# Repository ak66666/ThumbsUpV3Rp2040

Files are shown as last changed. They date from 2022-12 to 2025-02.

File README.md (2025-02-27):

# ThumbsUp! v3 RP2040-based 4x12 keyboard for Kailh Choc switches

Multilevel 44 Key Split Contoured Keyboard.
2-key Thumb Cluster

* RP2040 is soldered on the boards.
* TRS (3-wire) audio cable to connect the halves.
* Hot swap sockets for Kailh Choc switches.
* USB-C connectors.
* Connects to computer from either side, halves could be used separately.
 
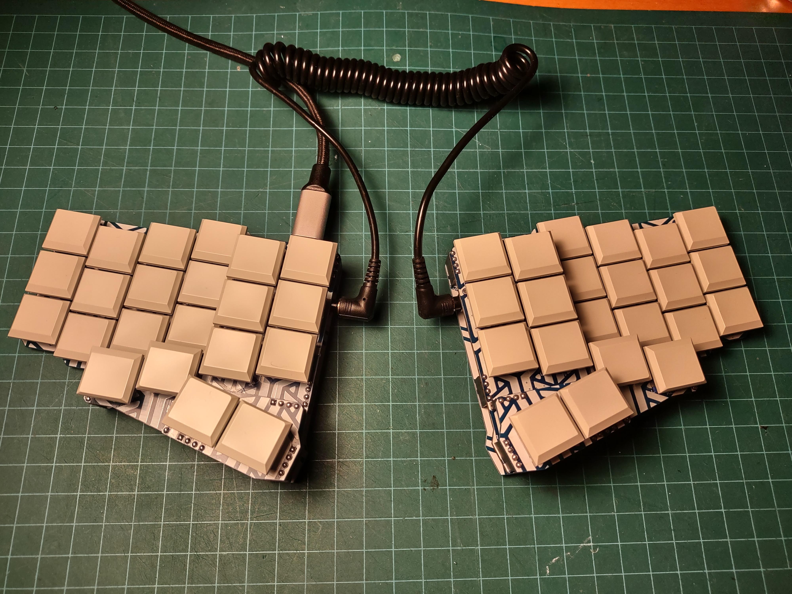
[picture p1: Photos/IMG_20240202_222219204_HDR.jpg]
Main view

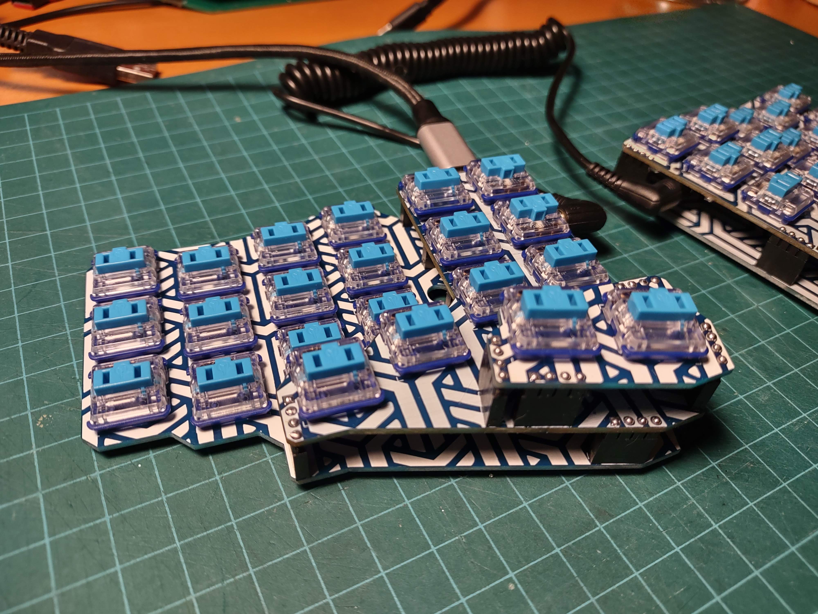
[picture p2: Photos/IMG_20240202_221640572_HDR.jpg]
Key caps removed


Other pictures in Photos folder.

# Firmware

Please refer to this article:
https://thumbsupkeyboards.blogspot.com/2024/02/source-files-and-default-firmware.html

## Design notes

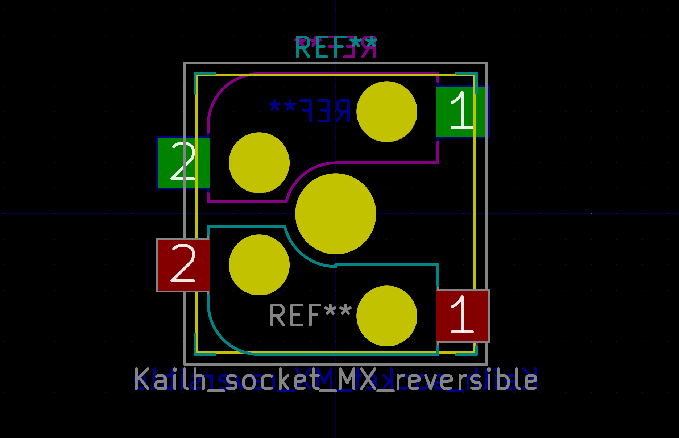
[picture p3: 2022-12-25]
keyswitches.pretty-master/images/Kailh_socket_MX_reversible_platemount.png

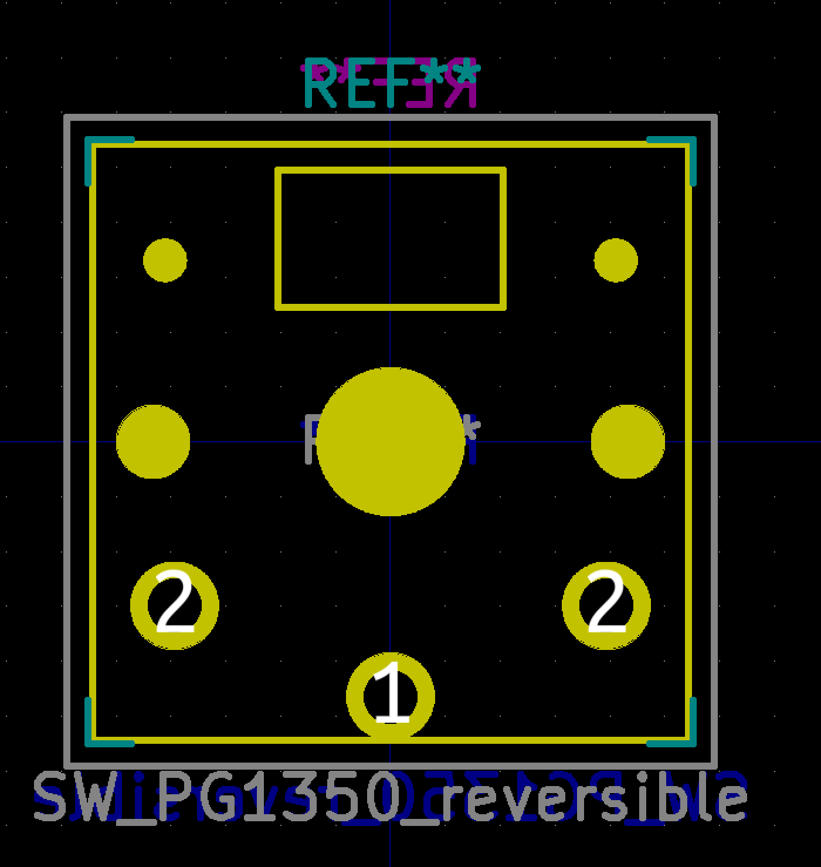
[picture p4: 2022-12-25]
keyswitches.pretty-master/images/SW_PG1350_reversible.png

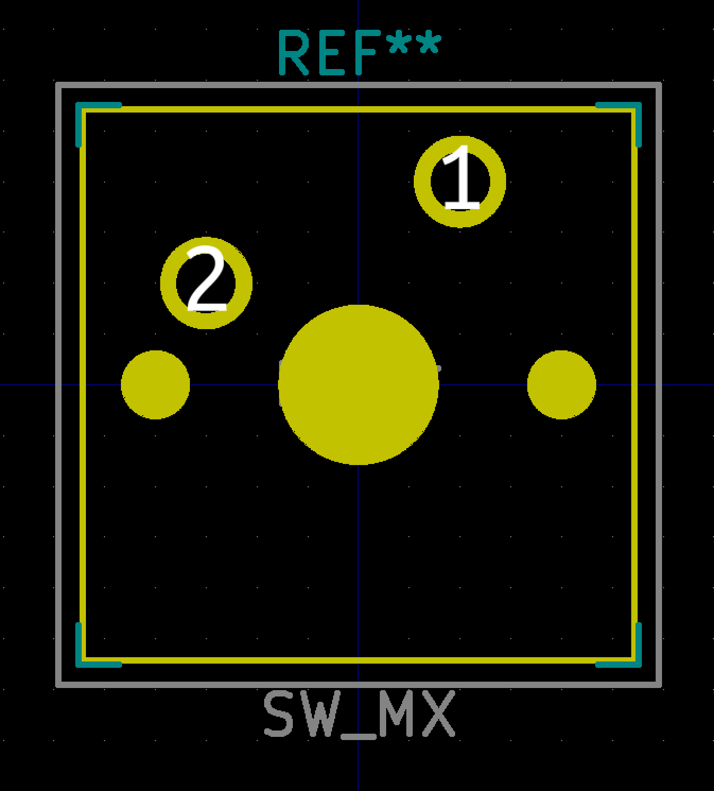
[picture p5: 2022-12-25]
keyswitches.pretty-master/images/SW_MX.png

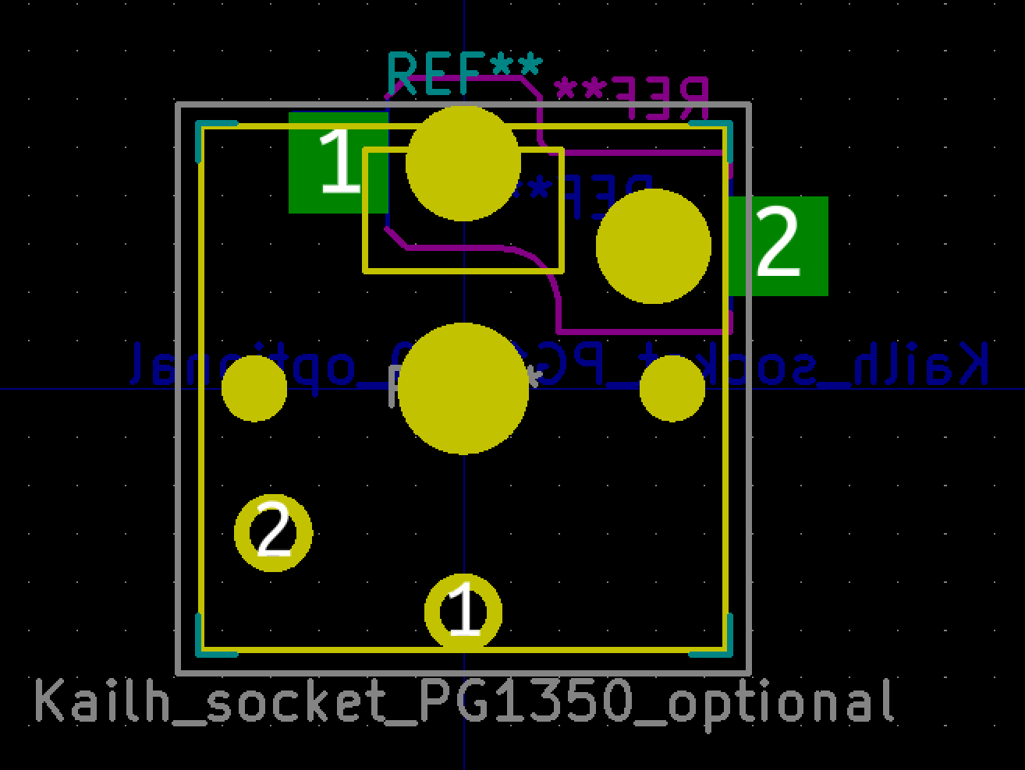
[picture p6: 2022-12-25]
keyswitches.pretty-master/images/Kailh_socket_PG1350_optional.png

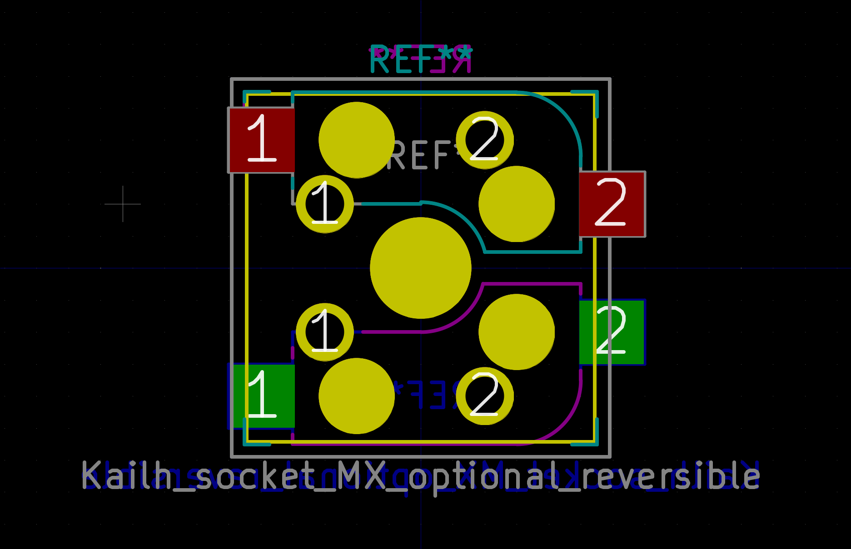
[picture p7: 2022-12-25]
keyswitches.pretty-master/images/Kailh_socket_MX_optional_reversible_platemount.png

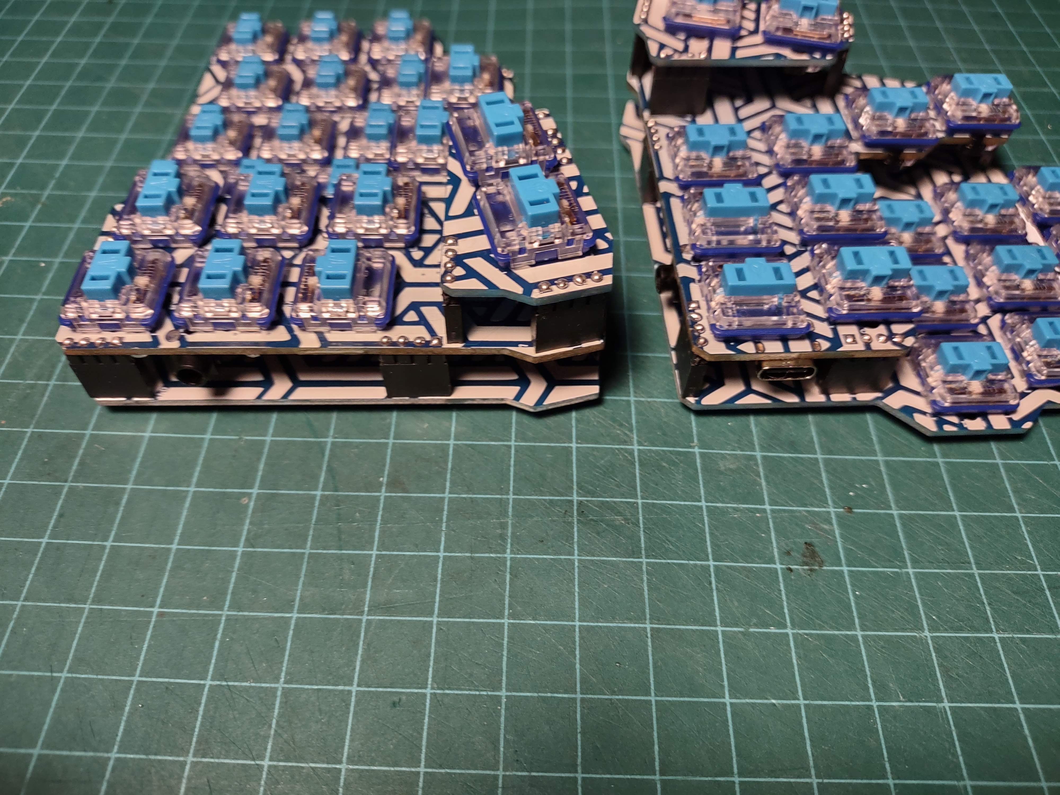
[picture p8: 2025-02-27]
Photos/IMG_20240202_221658583_HDR.jpg

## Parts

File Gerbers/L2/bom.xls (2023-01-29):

Comment | Designator | Footprint | JLCPCB Part #
27.4 | R2,R1 | R_0402_1005Metric | C274349
W25Q128JVSIM | IC2 | SOIC127P790X216-8N | C2613930
USB_C_Receptacle_USB2.0 | J32 | USB_C_Receptacle_Palconn_UTC16-G | C2927037
NCP1117-3.3_SOT223 | U1 | SOT-223-3_TabPin2 | C26537
27pF | C5,C4 | C_0402_1005Metric | C1557
1uF | C12,C3 | C_0402_1005Metric | C52923
0.1uF | C17,C16,C15,C14,C13,C10,C7,C6,C2 | C_0402_1005Metric | C2655418
5.1k | R9,R8,R4,R17,R9,R8,R4,R17 | R_0402_1005Metric | C25905
Polyfuse | F1 | Fuse_1206_3216Metric | C2836286
10uF | C11,C9 | C_0402_1005Metric | C15525
1k | R6 | R_0402_1005Metric | C11702
RP2040 | IC1 | QFN40P700X700X90-57N-D | C2040
10k | R3 | R_0402_1005Metric | C25744

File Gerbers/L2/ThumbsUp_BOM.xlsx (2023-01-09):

Comment | Designator | Footprint | JLCPCB Part #（optional）
27.4 | R2,R1 | R_0402_1005Metric
5.1k | R9,R8 | R_0402_1005Metric
10uF | C11,C9 | C_0402_1005Metric
5.1k | R4 | R_0805_2012Metric
1k | R6 | R_0402_1005Metric
10k | R3 | R_0402_1005Metric
0.1uF | C17,C16,C15,C14,C13,C10,C7,C6,C2 | C_0402_1005Metric
1uF | C12,C3 | C_0402_1005Metric
27pF | C5,C4 | C_0402_1005Metric
USB_C_Receptacle_USB2.0 | J32 | USB_C_Receptacle_Palconn_UTC16-G
STX-3501-3N | J36 | STX35013N
ABLS-12.000MHZ-B4-T | Y1 | HC%2f49US-(AT49)_1
NCP1117-3.3_SOT223 | U1 | SOT-223-3_TabPin2
TL1016AAF220QG | RUN1,BOOTSEL1 | TL1016AAF220QG
W25Q128JVSIM | IC2 | SOIC127P790X216-8N
RP2040 | IC1 | QFN40P700X700X90-57N-D
Polyfuse | F1 | Fuse_1206_3216Metric

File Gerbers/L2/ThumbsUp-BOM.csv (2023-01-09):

Id | Designator | Package | Quantity | Designation | Supplier and ref
1 | R2,R1 | R_0402_1005Metric | 2 | 27.4
2 | R9,R8 | R_0402_1005Metric | 2 | 5.1k
3 | C11,C9 | C_0402_1005Metric | 2 | 10uF
4 | R4 | R_0805_2012Metric | 1 | DNF
5 | R7 | R_0402_1005Metric | 1 | DNF
6 | R6 | R_0402_1005Metric | 1 | 1k
7 | R3 | R_0402_1005Metric | 1 | 10k
8 | C17,C16,C15,C14,C13,C10,C7,C6,C2 | C_0402_1005Metric | 9 | 0.1uF
9 | C12,C3 | C_0402_1005Metric | 2 | 1uF
10 | C5,C4 | C_0402_1005Metric | 2 | 27pF
11 | J32 | USB_C_Receptacle_Palconn_UTC16-G | 1 | USB_C_Receptacle_USB2.0
12 | J3 | PinSocket_1x04_P2.54mm_Vertical | 1 | Conn_01x04_Female
13 | J36 | STX35013N | 1 | STX-3501-3N
14 | J39,J45,J16 | PinHeader_1x04_P2.54mm_Vertical | 3 | Raiser_Male
15 | J17,J9,J13 | PinSocket_1x04_P2.54mm_Vertical | 3 | Raiser_Female
16 | MX19 | Kailh_socket_PG1350_optional | 1 | SwT
17 | MX14 | Kailh_socket_PG1350_optional | 1 | SwLALT
18 | MX15 | Kailh_socket_PG1350_optional | 1 | SwR
19 | MX17 | Kailh_socket_PG1350_optional | 1 | SwV
20 | MX20 | Kailh_socket_PG1350_optional | 1 | SwG
21 | MX21 | Kailh_socket_PG1350_optional | 1 | SwB
22 | MX10 | Kailh_socket_PG1350_optional | 1 | SwLWIN
23 | MX16 | Kailh_socket_PG1350_optional | 1 | SwF
24 | J1,J8,J2,J7 | PinHeader_1x04_P2.54mm_Vertical | 4 | Conn_01x04_Male
25 | Y1 | HC%2f49US-(AT49)_1 | 1 | ABLS-12.000MHZ-B4-T
26 | U1 | SOT-223-3_TabPin2 | 1 | NCP1117-3.3_SOT223
27 | RUN1,BOOTSEL1 | TL1016AAF220QG | 2 | TL1016AAF220QG
28 | IC2 | SOIC127P790X216-8N | 1 | W25Q128JVSIM
29 | IC1 | QFN40P700X700X90-57N-D | 1 | RP2040
30 | F1 | Fuse_1206_3216Metric | 1 | Polyfuse

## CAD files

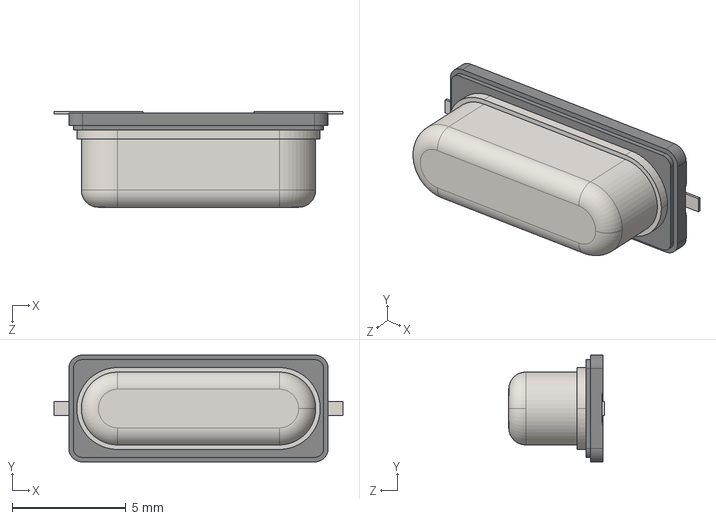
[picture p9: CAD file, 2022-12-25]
ABLS-12.000MHZ-B4-T/3D/ABLS-12.000MHZ-B4-T.stp
12.7 x 4.70 x 4.20 mm

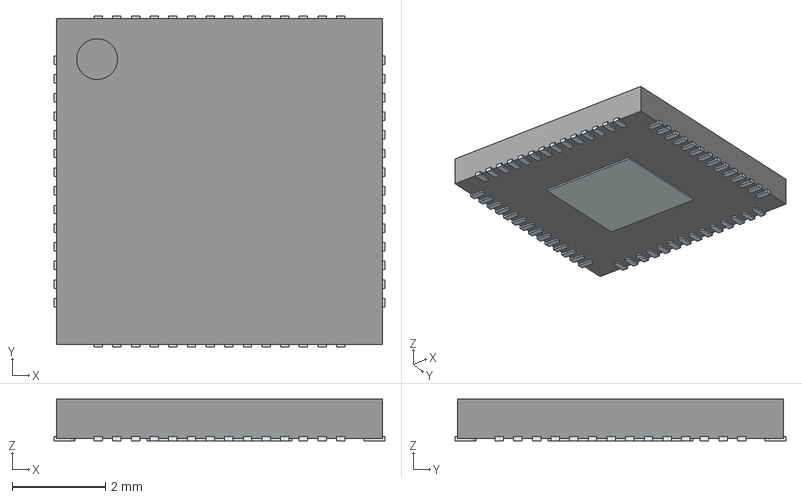
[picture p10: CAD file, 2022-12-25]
RP2040/3D/RP2040.stp
7.10 x 7.10 x 0.9 mm
ThermalPin
PinsArrayLR
PinsArrayTB

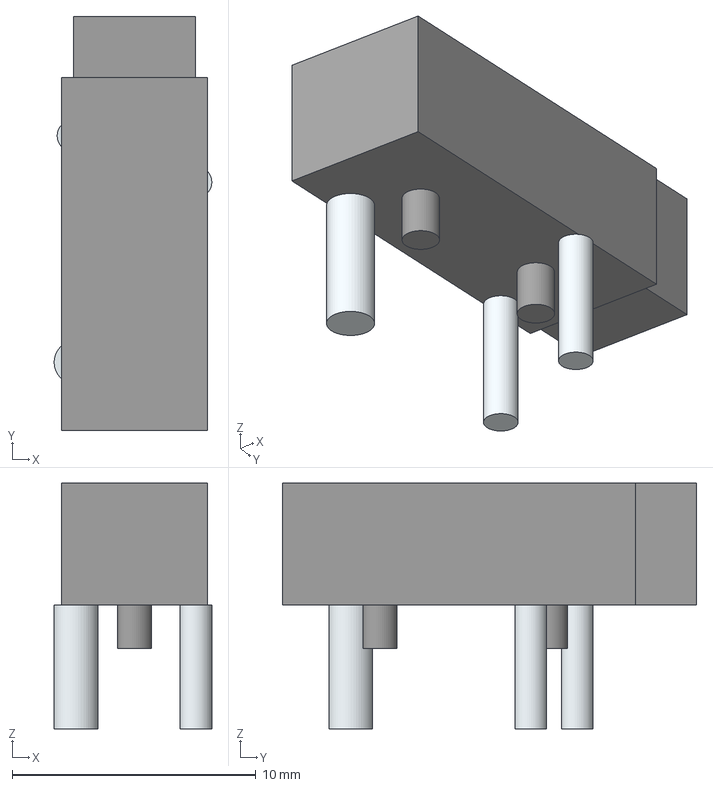
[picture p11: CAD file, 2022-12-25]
STX-3501-3N/3D/STX-3501-3N.stp
6.47 x 17.0 x 10.1 mm
Lugs
Leads

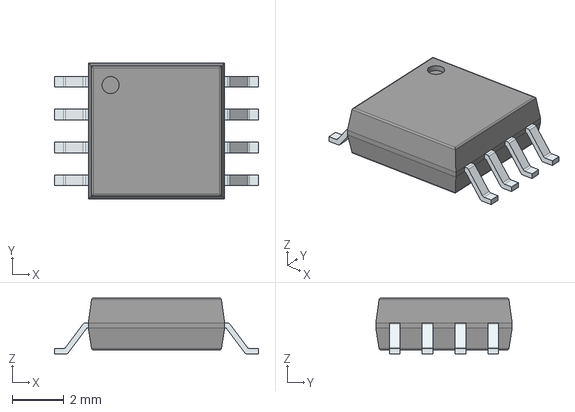
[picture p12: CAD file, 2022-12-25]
W25Q128JVSIM/3D/W25Q128JVSIM.stp
7.90 x 5.28 x 2.16 mm
PinsArrayLR

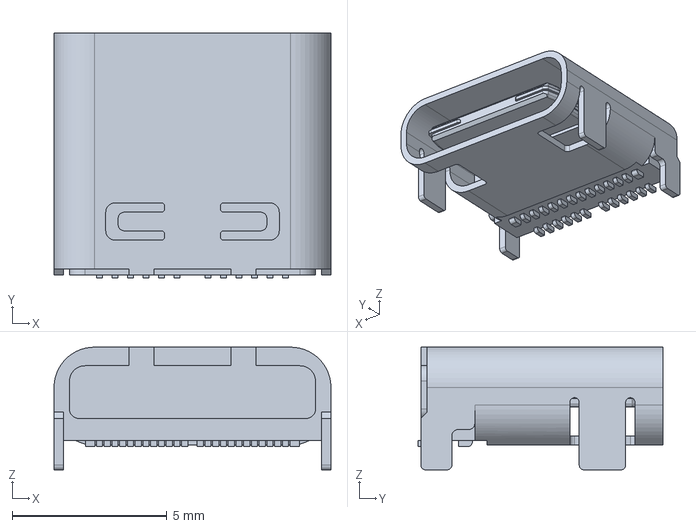
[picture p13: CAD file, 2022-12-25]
105450-0101/3D/105450-0101.stp
8.94 x 7.90 x 3.96 mm

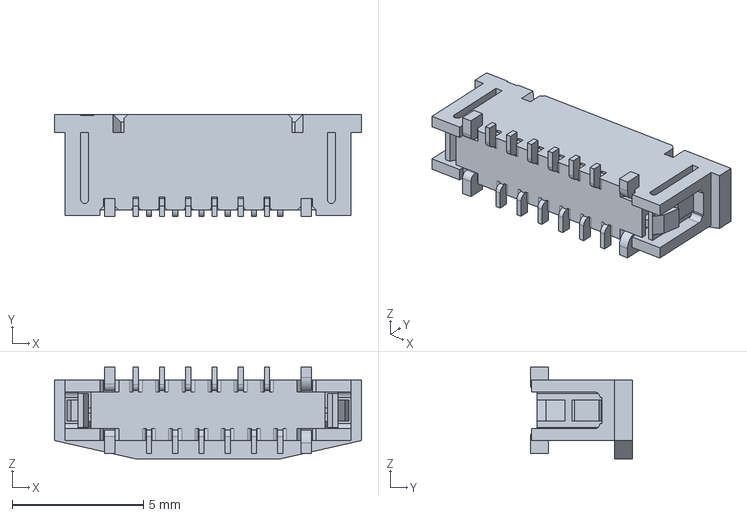
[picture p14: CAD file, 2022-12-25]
Molex 52559-1233/52559-1233/3D/52559-1233.stp
11.7 x 3.90 x 3.50 mm

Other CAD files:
ABLS-12.000MHZ-B4-T/Allegro/hc_49us-_at49__1.psm
ABLS-12.000MHZ-B4-T/DEHDL/abls_12.000mhz_b4_t/chips/chips.prt
EVQ-P7B01P/Allegro/evqp7b01p.psm
EVQ-P7B01P/DEHDL/evq_p7b01p/chips/chips.prt
Molex 52559-1233/52559-1233/Allegro/525591233.psm
Molex 52559-1233/52559-1233/DEHDL/52559_1233/chips/chips.prt
RP2040/Allegro/qfn40p700x700x90-57n-d.psm
RP2040/DEHDL/rp2040/chips/chips.prt
STX-3501-3N/Allegro/stx35013n.psm
STX-3501-3N/DEHDL/stx_3501_3n/chips/chips.prt
TL1016AAF220QG/Allegro/tl1016aaf220qg.psm
TL1016AAF220QG/DEHDL/tl1016aaf220qg/chips/chips.prt
W25Q128JVSIM/Allegro/soic127p790x216-8n.psm
W25Q128JVSIM/DEHDL/w25q128jvsim/chips/chips.prt

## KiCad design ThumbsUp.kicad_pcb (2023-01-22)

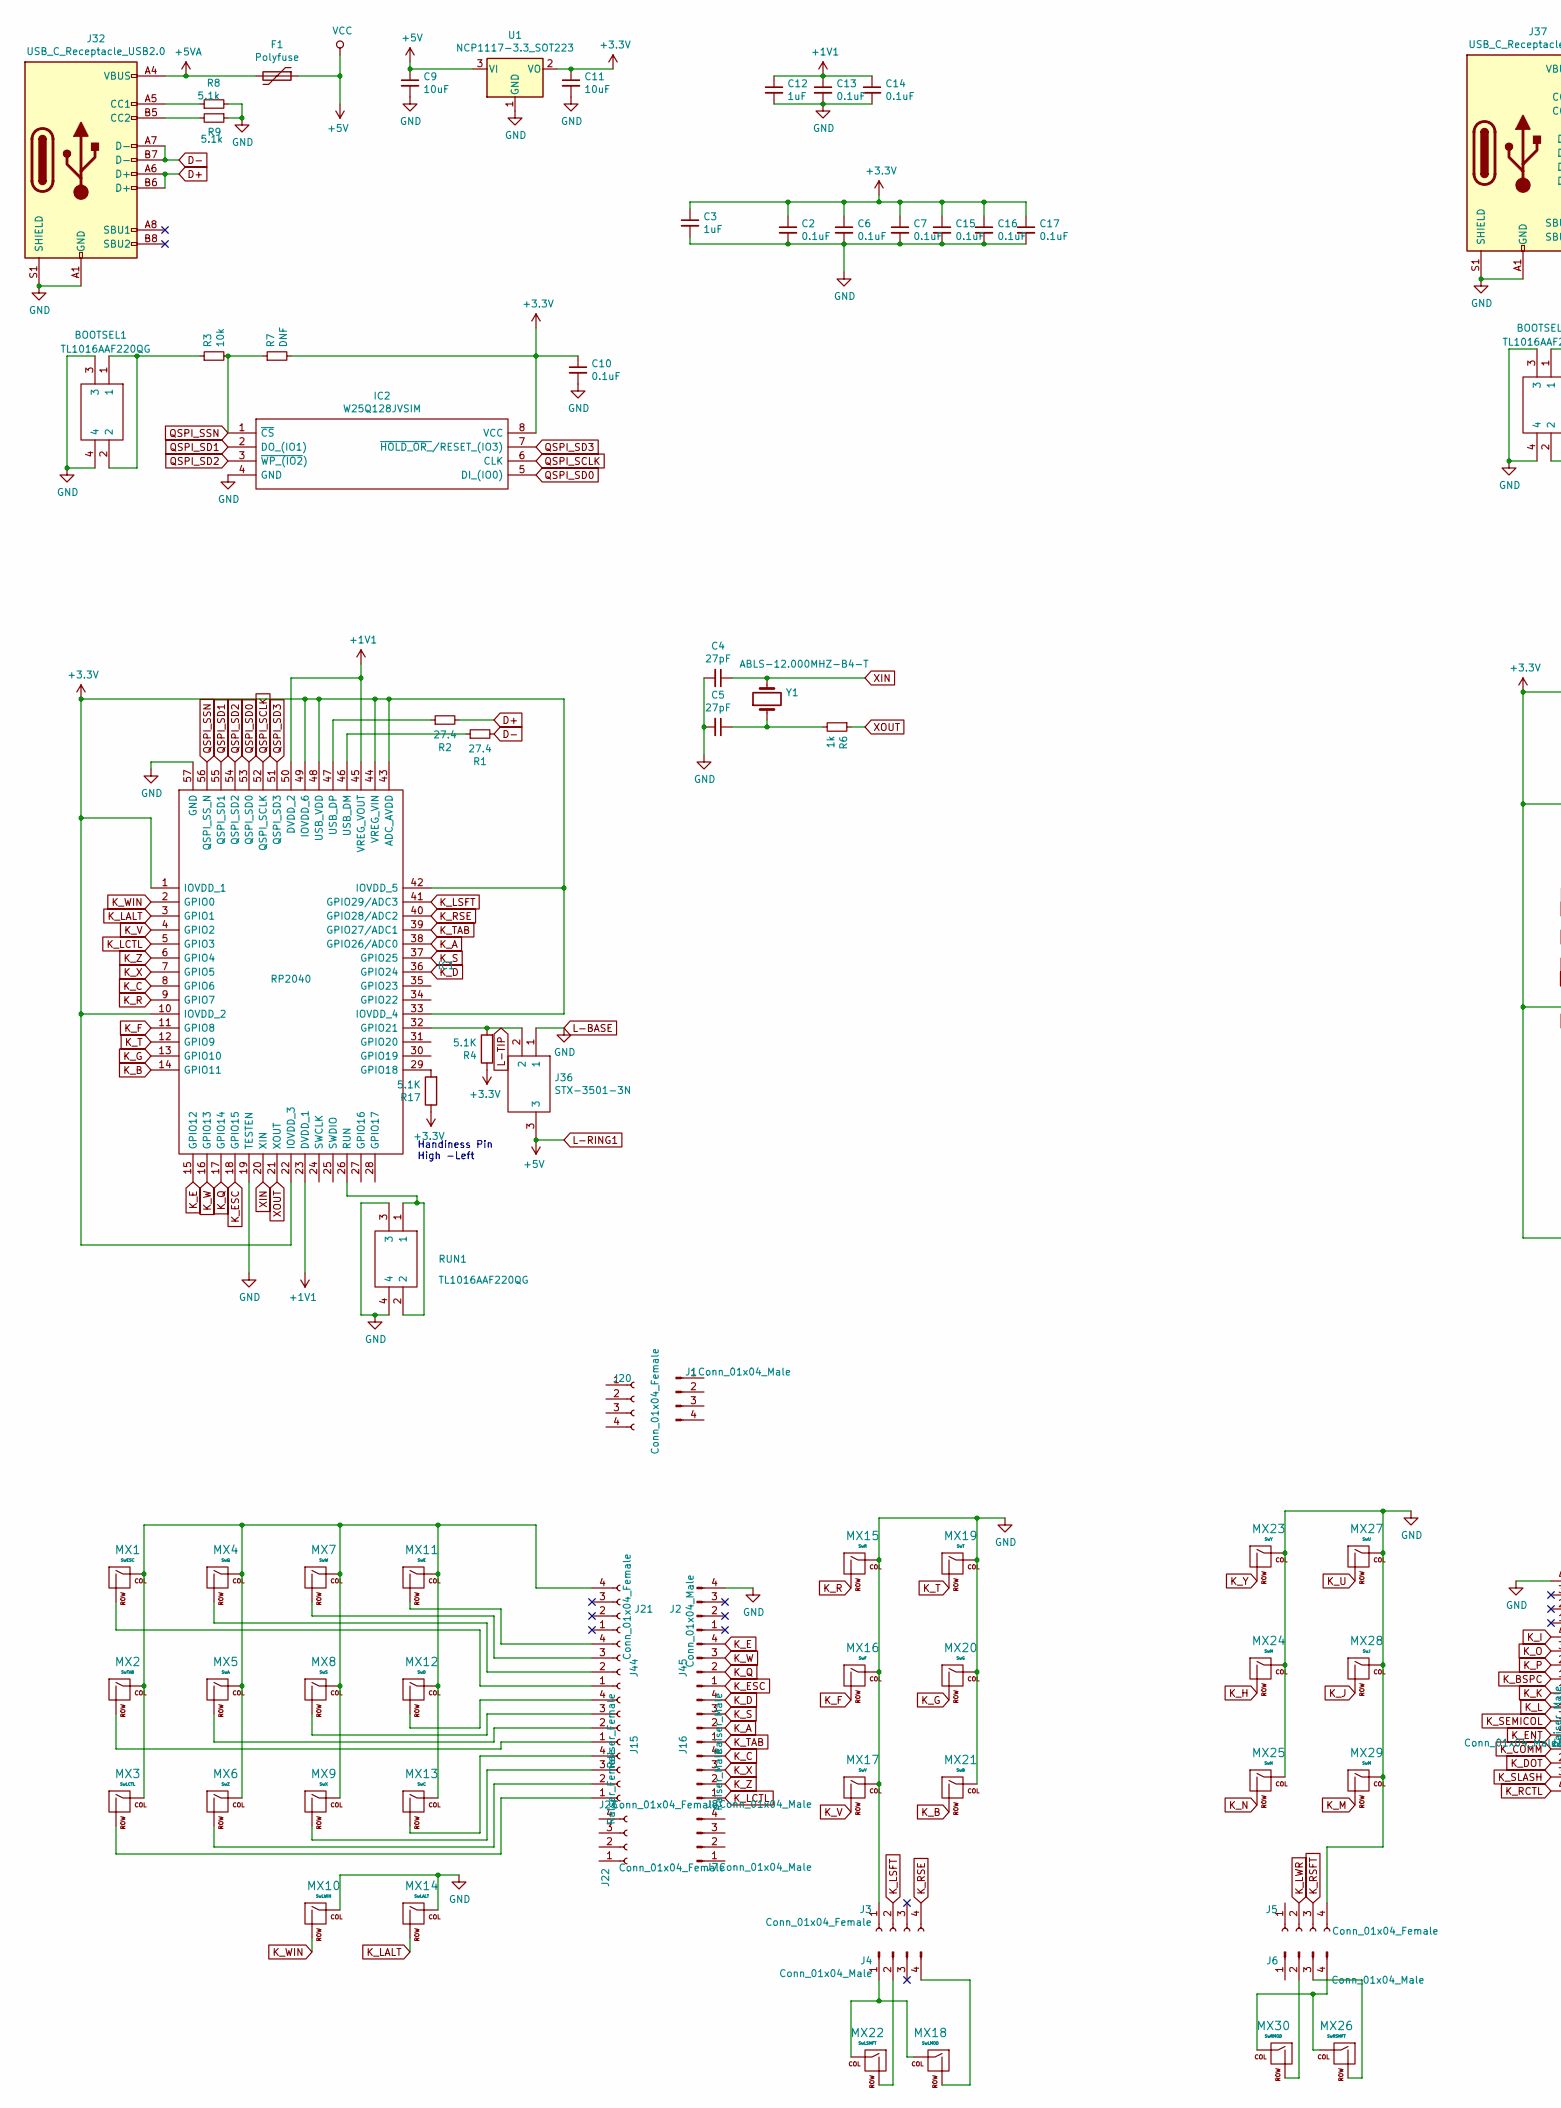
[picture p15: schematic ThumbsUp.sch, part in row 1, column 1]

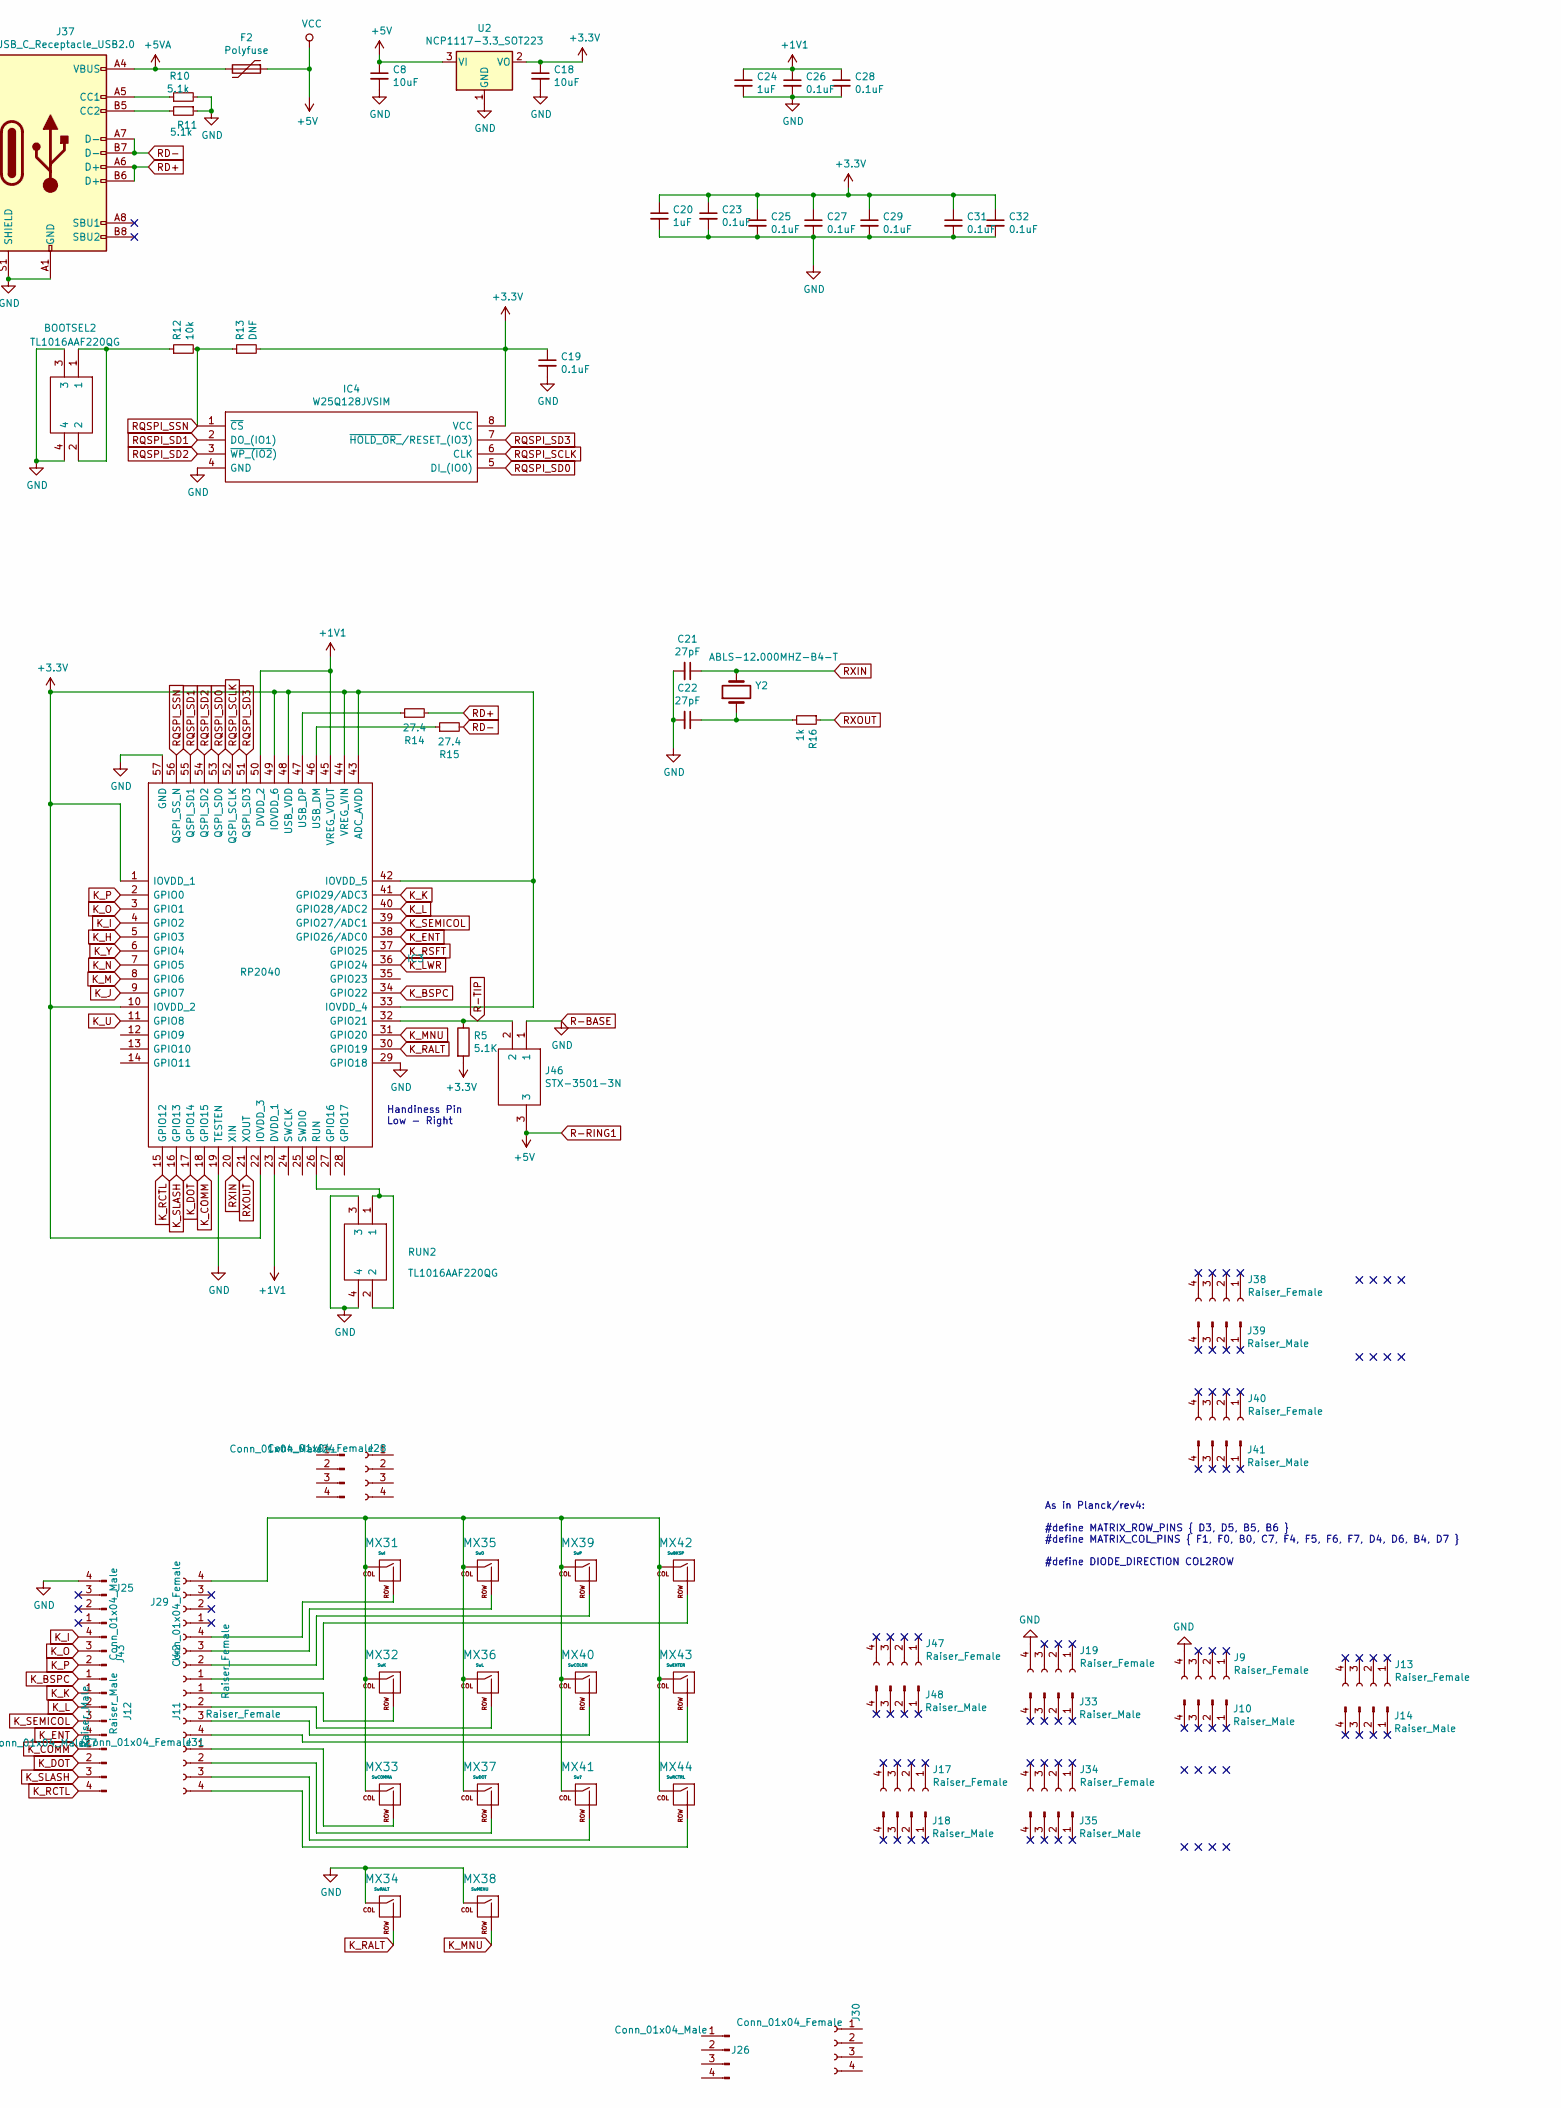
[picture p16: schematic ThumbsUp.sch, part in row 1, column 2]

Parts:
BOOTSEL1, BOOTSEL2: TL1016AAF220QG; Manufacturer_Part_Number TL1016AAF220QG; Mouser Part Number 612-TL1016AAF220QG
C2, C6, C7, C10, C13, C14, C15, C16, C17, C19, C23, C25, C26, C27, C28, C29, C31, C32: 0.1uF; C_0402_1005Metric
C3, C12, C20, C24: 1uF; C_0402_1005Metric
C4, C5, C21, C22: 27pF; C_0402_1005Metric
C8, C9, C11, C18: 10uF; C_0402_1005Metric
F1, F2: Polyfuse; Fuse_1206_3216Metric
IC1, IC3: RP2040; QFN40P700X700X90-57N-D; Manufacturer_Part_Number RP2040
IC2, IC4: W25Q128JVSIM; SOIC127P790X216-8N; Manufacturer_Part_Number W25Q128JVSIM; Mouser Part Number 454-W25Q128JVSIM
J1, J2, J4, J6, J7, J8, J24, J25, J26, J27: Conn_01x04_Male; PinHeader_1x04_P2.54mm_Vertical
J3, J5, J20, J21, J22, J23, J28, J29, J30, J31: Conn_01x04_Female; PinSocket_1x04_P2.54mm_Vertical
J9, J11, J13, J15, J17, J19, J34, J38, J40, J42, J44, J47: Raiser_Female; PinSocket_1x04_P2.54mm_Vertical
J10, J12, J14, J16, J18, J33, J35, J39, J41, J43, J45, J48: Raiser_Male; PinHeader_1x04_P2.54mm_Vertical
J32, J37: USB_C_Receptacle_USB2.0; USB_C_Receptacle_Palconn_UTC16-G
J36, J46: STX-3501-3N; STX35013N; Manufacturer_Part_Number STX-3501-3N; Mouser Part Number 806-STX-3501-3N
MX1: SwESC; Kailh_socket_PG1350_optional
MX2: SwTAB; Kailh_socket_PG1350_optional
MX3: SwLCTL; Kailh_socket_PG1350_optional
MX4: SwQ; Kailh_socket_PG1350_optional
MX5: SwA; Kailh_socket_PG1350_optional
MX6: SwZ; Kailh_socket_PG1350_optional
MX7: SwW; Kailh_socket_PG1350_optional
MX8: SwS; Kailh_socket_PG1350_optional
MX9: SwX; Kailh_socket_PG1350_optional
MX10: SwLWIN; Kailh_socket_PG1350_optional
MX11: SwE; Kailh_socket_PG1350_optional
MX12: SwD; Kailh_socket_PG1350_optional
MX13: SwC; Kailh_socket_PG1350_optional
MX14: SwLALT; Kailh_socket_PG1350_optional
MX15: SwR; Kailh_socket_PG1350_optional
MX16: SwF; Kailh_socket_PG1350_optional
MX17: SwV; Kailh_socket_PG1350_optional
MX18: SwLMOD; Kailh_socket_PG1350_optional
MX19: SwT; Kailh_socket_PG1350_optional
MX20: SwG; Kailh_socket_PG1350_optional
MX21: SwB; Kailh_socket_PG1350_optional
MX22: SwLSHFT; Kailh_socket_PG1350_optional
MX23: SwY; Kailh_socket_PG1350_optional
MX24: SwH; Kailh_socket_PG1350_optional
MX25: SwN; Kailh_socket_PG1350_optional
MX26: SwRSHFT; Kailh_socket_PG1350_optional
MX27: SwU; Kailh_socket_PG1350_optional
MX28: SwJ; Kailh_socket_PG1350_optional
MX29: SwM; Kailh_socket_PG1350_optional
MX30: SwRMOD; Kailh_socket_PG1350_optional
MX31: SwI; Kailh_socket_PG1350_optional
MX32: SwK; Kailh_socket_PG1350_optional
MX33: SwCOMMA; Kailh_socket_PG1350_optional
MX34: SwRALT; Kailh_socket_PG1350_optional
MX35: SwO; Kailh_socket_PG1350_optional
MX36: SwL; Kailh_socket_PG1350_optional
MX37: SwDOT; Kailh_socket_PG1350_optional
MX38: SwMENU; Kailh_socket_PG1350_optional
MX39: SwP; Kailh_socket_PG1350_optional
MX40: SwCOLON; Kailh_socket_PG1350_optional
MX41: Sw?; Kailh_socket_PG1350_optional
MX42: SwBKSP; Kailh_socket_PG1350_optional
MX43: SwENTER; Kailh_socket_PG1350_optional
MX44: SwRCTRL; Kailh_socket_PG1350_optional
R1, R2, R14, R15: 27.4; R_0402_1005Metric
R3, R12: 10k; R_0402_1005Metric
R4, R5, R17: 5.1K; R_0402_1005Metric
R6, R16: 1k; R_0402_1005Metric
R7, R13: DNF; R_0402_1005Metric
R8, R9, R10, R11: 5.1k; R_0402_1005Metric
RUN1, RUN2: TL1016AAF220QG; Manufacturer_Part_Number TL1016AAF220QG; Mouser Part Number 612-TL1016AAF220QG
U1, U2: NCP1117-3.3_SOT223; SOT-223-3_TabPin2
Y1, Y2: ABLS-12.000MHZ-B4-T; HC%2f49US-(AT49)_1

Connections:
+1V1: C12.1, C13.1, C14.1, C24.1, C26.1, C28.1, IC1.23 (DVDD_1), IC1.45 (VREG_VOUT), IC1.50 (DVDD_2), IC3.23 (DVDD_1), IC3.45 (VREG_VOUT), IC3.50 (DVDD_2)
+3V3: C2.1, C3.1, C6.1, C7.1, C10.1, C11.1, C15.1, C16.1, C17.1, C18.1, C19.1, C20.1, C23.1, C25.1, C27.1, C29.1, C31.1, C32.1, IC1.1 (IOVDD_1), IC1.10 (IOVDD_2), IC1.22 (IOVDD_3), IC1.33 (IOVDD_4), IC1.42 (IOVDD_5), IC1.43 (ADC_AVDD), IC1.44 (VREG_VIN), IC1.48 (USB_VDD), IC1.49 (IOVDD_6), IC2.8 (VCC), IC3.1 (IOVDD_1), IC3.10 (IOVDD_2), IC3.22 (IOVDD_3), IC3.33 (IOVDD_4), IC3.42 (IOVDD_5), IC3.43 (ADC_AVDD), IC3.44 (VREG_VIN), IC3.48 (USB_VDD), IC3.49 (IOVDD_6), IC4.8 (VCC), R4.1, R5.2, R7.2, R13.2, R17.1, U1.2 (VO), U2.2 (VO)
+5VA: F1.2, F2.2, J32.A4 (VBUS), J32.A9 (VBUS), J32.B4 (VBUS), J32.B9 (VBUS), J37.A4 (VBUS), J37.A9 (VBUS), J37.B4 (VBUS), J37.B9 (VBUS)
D+: J32.A6 (D+), J32.B6 (D+), R2.2
D-: J32.A7 (D-), J32.B7 (D-), R1.2
K_A: IC1.38 (GPIO26/ADC0), J16.2
K_B: IC1.14 (GPIO11), MX21.2 (ROW)
K_BSPC: IC3.34 (GPIO22), J43.1
K_C: IC1.8 (GPIO6), J8.4
K_COMM: IC3.18 (GPIO15), J27.1
K_D: IC1.36 (GPIO24), J16.4
K_DOT: IC3.17 (GPIO14), J27.2
K_E: IC1.15 (GPIO12), J45.4
K_ENT: IC3.38 (GPIO26/ADC0), J12.4
K_ESC: IC1.18 (GPIO15), J45.1
K_F: IC1.11 (GPIO8), MX16.2 (ROW)
K_G: IC1.13 (GPIO10), MX20.2 (ROW)
K_H: IC3.5 (GPIO3), MX24.2 (ROW)
K_I: IC3.4 (GPIO2), J43.4
K_J: IC3.9 (GPIO7), MX28.2 (ROW)
K_K: IC3.41 (GPIO29/ADC3), J12.1
K_L: IC3.40 (GPIO28/ADC2), J12.2
K_LALT: IC1.3 (GPIO1), MX14.2 (ROW)
K_LCTL: IC1.5 (GPIO3), J8.1
K_LSFT: IC1.41 (GPIO29/ADC3), J3.2
K_LWR: IC3.36 (GPIO24), J5.2
K_M: IC3.8 (GPIO6), MX29.2 (ROW)
K_MNU: IC3.31 (GPIO20), MX38.2 (ROW)
K_N: IC3.7 (GPIO5), MX25.2 (ROW)
K_O: IC3.3 (GPIO1), J43.3
K_P: IC3.2 (GPIO0), J43.2
K_Q: IC1.17 (GPIO14), J45.2
K_R: IC1.9 (GPIO7), MX15.2 (ROW)
K_RALT: IC3.30 (GPIO19), MX34.2 (ROW)
K_RCTL: IC3.15 (GPIO12), J27.4
K_RSE: IC1.40 (GPIO28/ADC2), J3.4
K_RSFT: IC3.37 (GPIO25), J5.3
K_S: IC1.37 (GPIO25), J16.3
K_SEMICOL: IC3.39 (GPIO27/ADC1), J12.3
K_SLASH: IC3.16 (GPIO13), J27.3
K_T: IC1.12 (GPIO9), MX19.2 (ROW)
K_TAB: IC1.39 (GPIO27/ADC1), J16.1
K_U: IC3.11 (GPIO8), MX27.2 (ROW)
K_V: IC1.4 (GPIO2), MX17.2 (ROW)
K_W: IC1.16 (GPIO13), J45.3
K_WIN: IC1.2 (GPIO0), MX10.2 (ROW)
K_X: IC1.7 (GPIO5), J8.3
K_Y: IC3.6 (GPIO4), MX23.2 (ROW)
K_Z: IC1.6 (GPIO4), J8.2
L-BASE: BOOTSEL1.3, BOOTSEL1.4, BOOTSEL2.3, BOOTSEL2.4, C2.2, C3.2, C4.2, C5.2, C6.2, C7.2, C8.2, C9.2, C10.2, C11.2, C12.2, C13.2, C14.2, C15.2, C16.2, C17.2, C18.2, C19.2, C20.2, C21.2, C22.2, C23.2, C24.2, C25.2, C26.2, C27.2, C28.2, C29.2, C31.2, C32.2, IC1.19 (TESTEN), IC1.57 (GND), IC2.4 (GND), IC3.19 (TESTEN), IC3.29 (GPIO18), IC3.57 (GND), IC4.4 (GND), J2.4, J3.1, J5.4, J9.4, J19.4, J25.4, J32.A1 (GND), J32.A12 (GND), J32.B1 (GND), J32.B12 (GND), J32.S1 (SHIELD), J36.1, J37.A1 (GND), J37.A12 (GND), J37.B1 (GND), J37.B12 (GND), J37.S1 (SHIELD), J46.1, MX10.1 (COL), MX14.1 (COL), MX15.1 (COL), MX16.1 (COL), MX17.1 (COL), MX19.1 (COL), MX20.1 (COL), MX21.1 (COL), MX23.1 (COL), MX24.1 (COL), MX25.1 (COL), MX27.1 (COL), MX28.1 (COL), MX29.1 (COL), MX34.1 (COL), MX38.1 (COL), R8.2, R9.1, R10.2, R11.1, RUN1.3, RUN1.4, RUN2.3, RUN2.4, U1.1 (GND), U2.1 (GND)
L-RING1: C8.1, C9.1, F1.1, F2.1, J36.3, J46.3, U1.3 (VI), U2.3 (VI)
L-TIP: IC1.32 (GPIO21), J36.2, R4.2
unnamed: BOOTSEL1.1, BOOTSEL1.2, R3.1
unnamed: BOOTSEL2.1, BOOTSEL2.2, R12.1
unnamed: C5.1, R6.2, Y1.1
unnamed: C22.1, R16.2, Y2.1
unnamed: IC1.26 (RUN), RUN1.1, RUN1.2
unnamed: IC1.29 (GPIO18), R17.2
unnamed: IC1.46 (USB_DM), R1.1
unnamed: IC1.47 (USB_DP), R2.1
unnamed: IC3.26 (RUN), RUN2.1, RUN2.2
unnamed: IC3.46 (USB_DM), R15.1
unnamed: IC3.47 (USB_DP), R14.1
unnamed: J4.1, MX18.1 (COL), MX22.1 (COL)
unnamed: J4.2, MX22.2 (ROW)
unnamed: J4.4, MX18.2 (ROW)
unnamed: J6.2, MX30.2 (ROW)
unnamed: J6.3, MX26.2 (ROW)
unnamed: J6.4, MX26.1 (COL), MX30.1 (COL)
unnamed: J11.1, MX32.2 (ROW)
unnamed: J11.2, MX36.2 (ROW)
unnamed: J11.3, MX40.2 (ROW)
unnamed: J11.4, MX43.2 (ROW)
unnamed: J15.1, MX2.2 (ROW)
unnamed: J15.2, MX5.2 (ROW)
unnamed: J15.3, MX8.2 (ROW)
unnamed: J15.4, MX12.2 (ROW)
unnamed: J21.4, MX1.1 (COL), MX2.1 (COL), MX3.1 (COL), MX4.1 (COL), MX5.1 (COL), MX6.1 (COL), MX7.1 (COL), MX8.1 (COL), MX9.1 (COL), MX11.1 (COL), MX12.1 (COL), MX13.1 (COL)
unnamed: J23.1, MX3.2 (ROW)
unnamed: J23.2, MX6.2 (ROW)
unnamed: J23.3, MX9.2 (ROW)
unnamed: J23.4, MX13.2 (ROW)
unnamed: J29.4, MX31.1 (COL), MX32.1 (COL), MX33.1 (COL), MX35.1 (COL), MX36.1 (COL), MX37.1 (COL), MX39.1 (COL), MX40.1 (COL), MX41.1 (COL), MX42.1 (COL), MX43.1 (COL), MX44.1 (COL)
unnamed: J31.1, MX33.2 (ROW)
unnamed: J31.2, MX37.2 (ROW)
unnamed: J31.3, MX41.2 (ROW)
unnamed: J31.4, MX44.2 (ROW)
unnamed: J32.A5 (CC1), R8.1
unnamed: J32.B5 (CC2), R9.2
unnamed: J37.A5 (CC1), R10.1
unnamed: J37.B5 (CC2), R11.2
unnamed: J42.1, MX42.2 (ROW)
unnamed: J42.2, MX39.2 (ROW)
unnamed: J42.3, MX35.2 (ROW)
unnamed: J42.4, MX31.2 (ROW)
unnamed: J44.1, MX1.2 (ROW)
unnamed: J44.2, MX4.2 (ROW)
unnamed: J44.3, MX7.2 (ROW)
unnamed: J44.4, MX11.2 (ROW)
QSPI_SCLK: IC1.52 (QSPI_SCLK), IC2.6 (CLK)
QSPI_SD0: IC1.53 (QSPI_SD0), IC2.5 (DI_(IO0))
QSPI_SD1: IC1.55 (QSPI_SD1), IC2.2 (DO_(IO1))
QSPI_SD2: IC1.54 (QSPI_SD2), IC2.3 (~WP_(IO2))
QSPI_SD3: IC1.51 (QSPI_SD3), IC2.7 (~HOLD_OR_~/RESET_(IO3))
QSPI_SSN: IC1.56 (QSPI_SS_N), IC2.1 (~CS), R3.2, R7.1
R-TIP: IC3.32 (GPIO21), J46.2, R5.1
RD+: J37.A6 (D+), J37.B6 (D+), R14.2
RD-: J37.A7 (D-), J37.B7 (D-), R15.2
RQSPI_SCLK: IC3.52 (QSPI_SCLK), IC4.6 (CLK)
RQSPI_SD0: IC3.53 (QSPI_SD0), IC4.5 (DI_(IO0))
RQSPI_SD1: IC3.55 (QSPI_SD1), IC4.2 (DO_(IO1))
RQSPI_SD2: IC3.54 (QSPI_SD2), IC4.3 (~WP_(IO2))
RQSPI_SD3: IC3.51 (QSPI_SD3), IC4.7 (~HOLD_OR_~/RESET_(IO3))
RQSPI_SSN: IC3.56 (QSPI_SS_N), IC4.1 (~CS), R12.2, R13.1
RXIN: C21.1, IC3.20 (XIN), Y2.2
RXOUT: IC3.21 (XOUT), R16.1
XIN: C4.1, IC1.20 (XIN), Y1.2
XOUT: IC1.21 (XOUT), R6.1

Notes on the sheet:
As in Planck/rev4: #define MATRIX_ROW_PINS { D3, D5, B5, B6 } #define MATRIX_COL_PINS { F1, F0, B0, C7, F4, F5, F6, F7, D4, D6, B4, D7 } #define DIODE_DIRECTION COL2ROW
Handiness Pin High -Left
Handiness Pin Low - Right

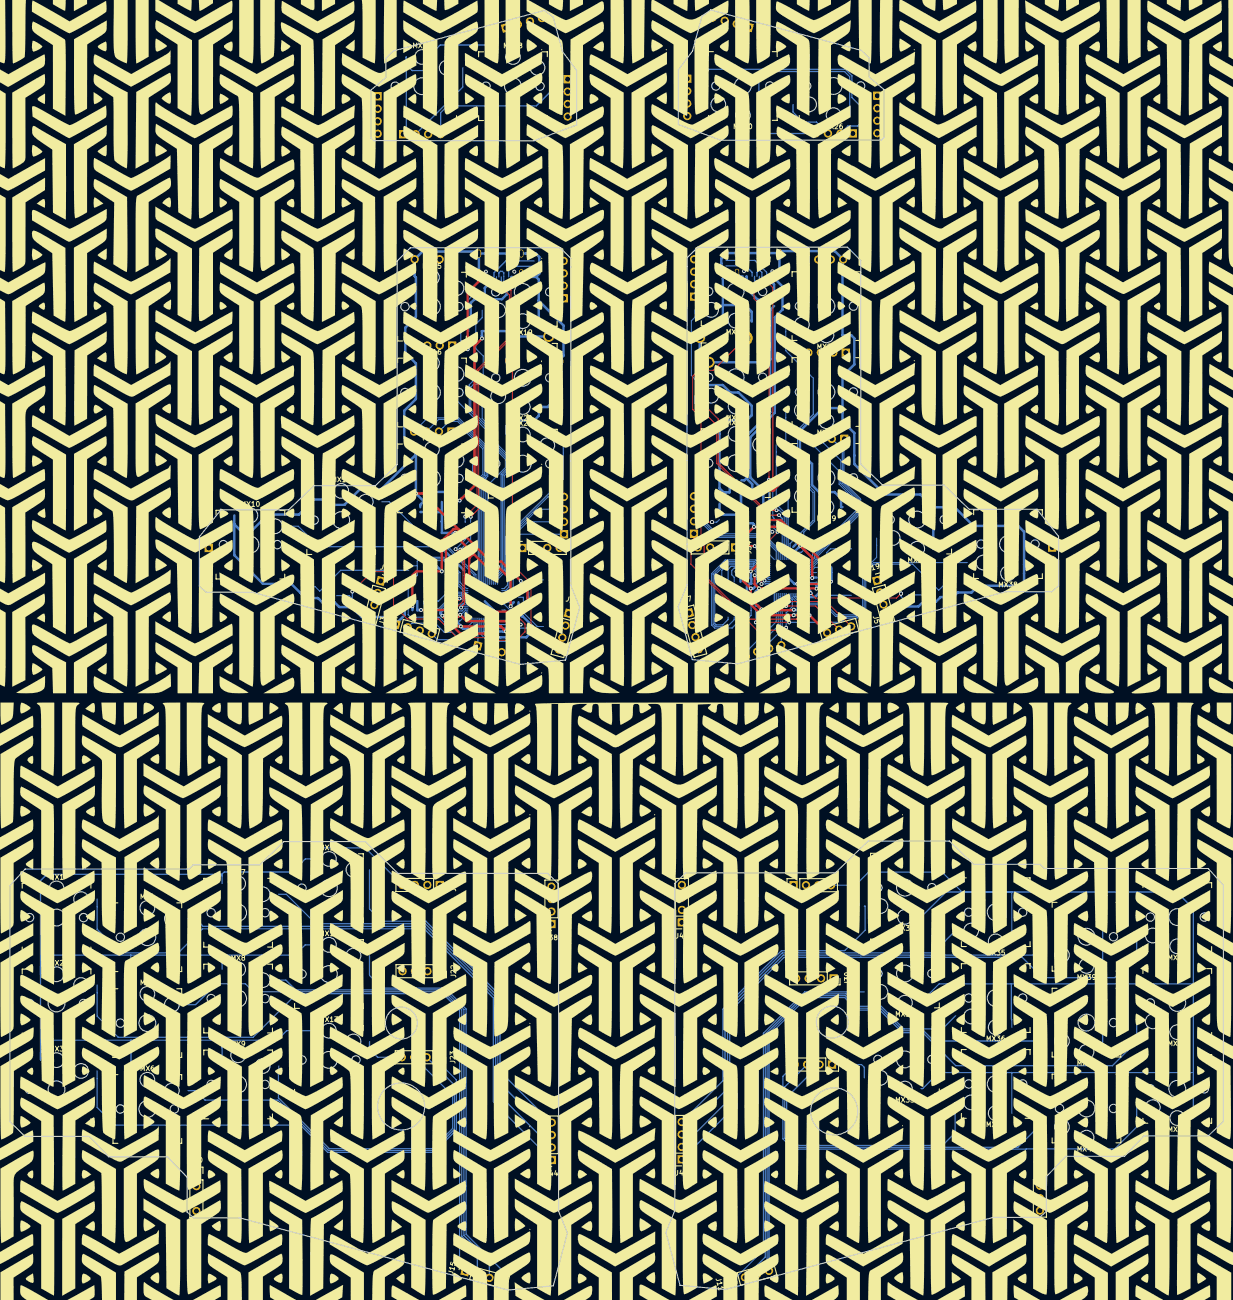
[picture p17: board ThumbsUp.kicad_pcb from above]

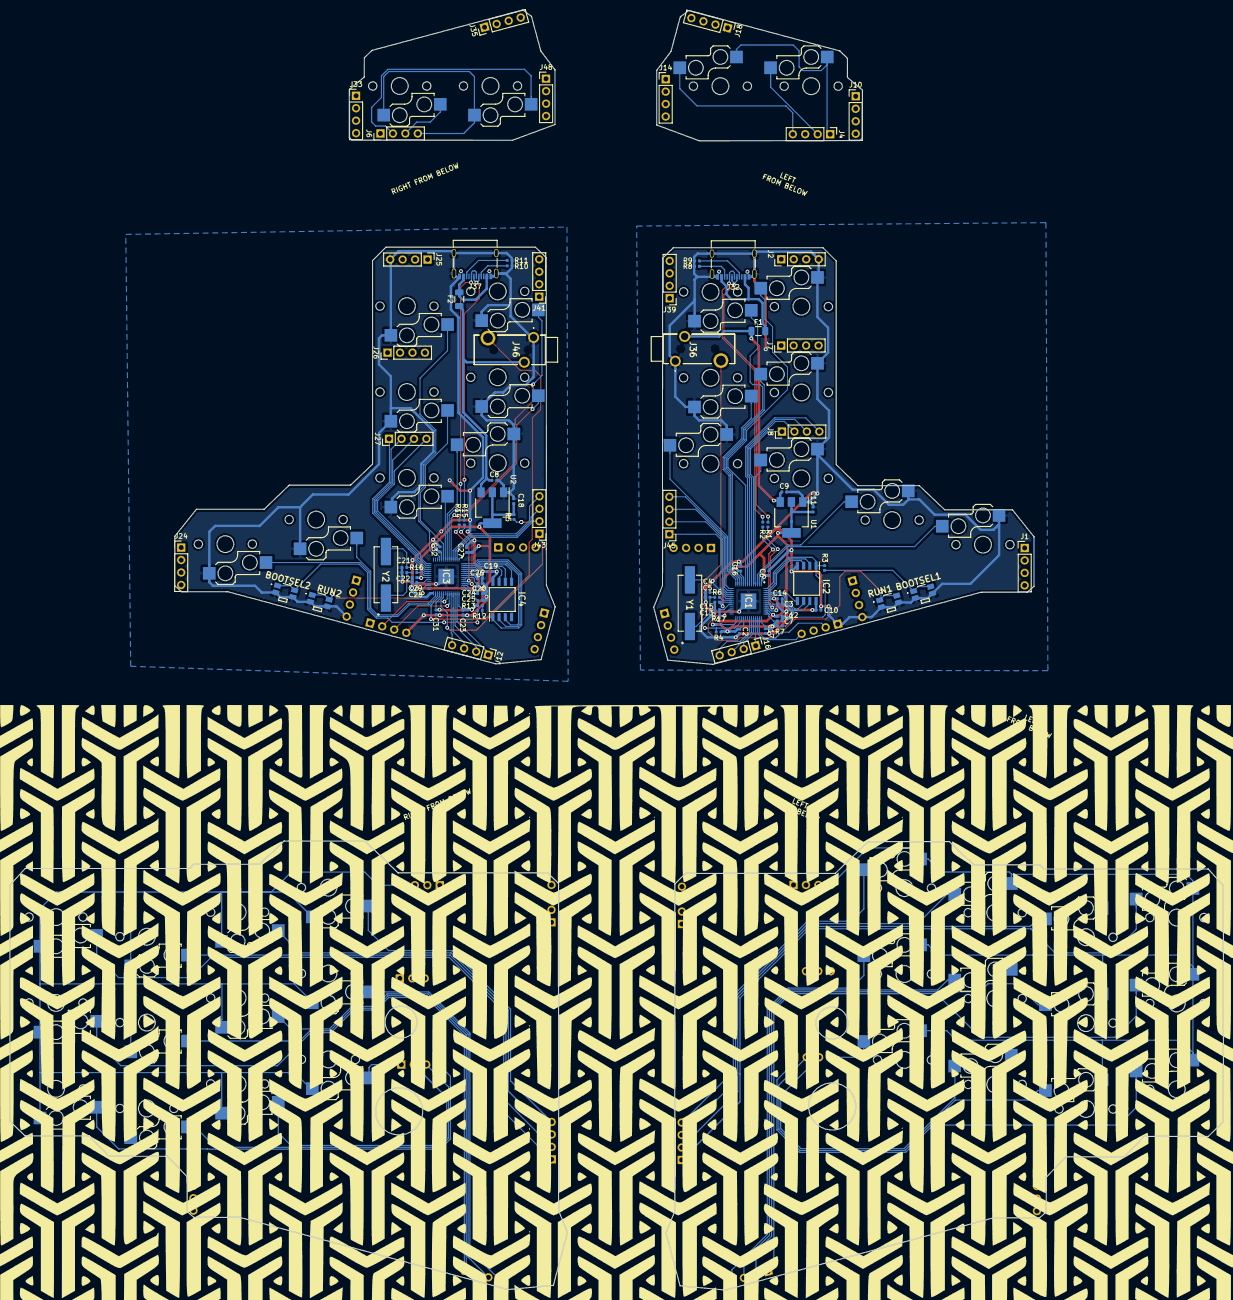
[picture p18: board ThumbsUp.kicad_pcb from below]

Board: 2 copper layers, 247.3 x 260.9 mm, 153 parts (87 on the bottom side), 118 nets.

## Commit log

2022-12-25 Initial layout of v3 created
    [105450-0101.stp, 52559-1233.stp, 525591233.psm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]
2022-12-26 Prepared the boards to be split
    [ThumbsUp.sch]
2022-12-26 Added audio connector
    [ThumbsUp.sch]
2022-12-26 Rearranged the header pins to match the actual positions.
    [ThumbsUp.kicad_pcb, ThumbsUp.sch]
2022-12-26 Reviewed the basic layout
    [ThumbsUp.sch]
2022-12-26 Traced the top and bottom plates.
    [ThumbsUp.kicad_pcb, ThumbsUp.sch]
2022-12-26 Retracing the plates.
    [ThumbsUp.kicad_pcb, ThumbsUp.sch]
2022-12-27 Tracing the plates.
    [ThumbsUp.kicad_pcb, ThumbsUp.sch]
2022-12-30 Somewhat finished the PCB tracing
    [ThumbsUp.kicad_pcb, ThumbsUp.sch]
2023-01-01 Added a missing line SS-N
    [ThumbsUp.kicad_pcb, ThumbsUp.sch]
2023-01-08 Added mounting holes, silkscreens
    [ThumbsUp.kicad_pcb]
2023-01-09 Generated Gerbers, no assebly files yet
    [ThumbsUp-B_Cu.gbr, ThumbsUp-B_Paste.gbr, ThumbsUp-B_SilkS.gbr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]
2023-01-09 Added BOM, fixed the placement files
    [ThumbsUp-BOM.csv, ThumbsUp.sch, ThumbsUp_BOM.xlsx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]
2023-01-22 Fixed the missing connectors and handiness pins
    [ThumbsUp-B_Cu.gbr, ThumbsUp-B_Mask.gbr, ThumbsUp-B_Paste.gbr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]
2023-01-28 Gerbers regenerated for L2, R2
    [ThumbsUp-B_Cu.gbr, ThumbsUp-B_Mask.gbr, ThumbsUp-B_Paste.gbr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]
2023-01-28 Updated BOM, POS files
    [bom.xls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]
2023-01-29 Updated the readme file.
    [bom.xls]
2025-02-27 ThumbsUp v3: Updated description.
    [ThumbsUp.sch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]
